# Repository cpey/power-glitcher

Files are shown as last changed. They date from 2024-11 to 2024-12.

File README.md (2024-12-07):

# Power Glitcher

Power glitcher circuit for voltage fault injection. Similar to [1], it includes
a DAC, a non-inverting amplification stage, and a push-pull follower output
circuit.

The board can function as ON/OFF switch, bypassing the DAC, by connecting a GPIO
output to the J5 connector and short-circuiting JP1. Refer to the
[schematic](https://github.com/cpey/power-glitcher/blob/main/power_glitcher/power_glitcher.pdf)
for more details.

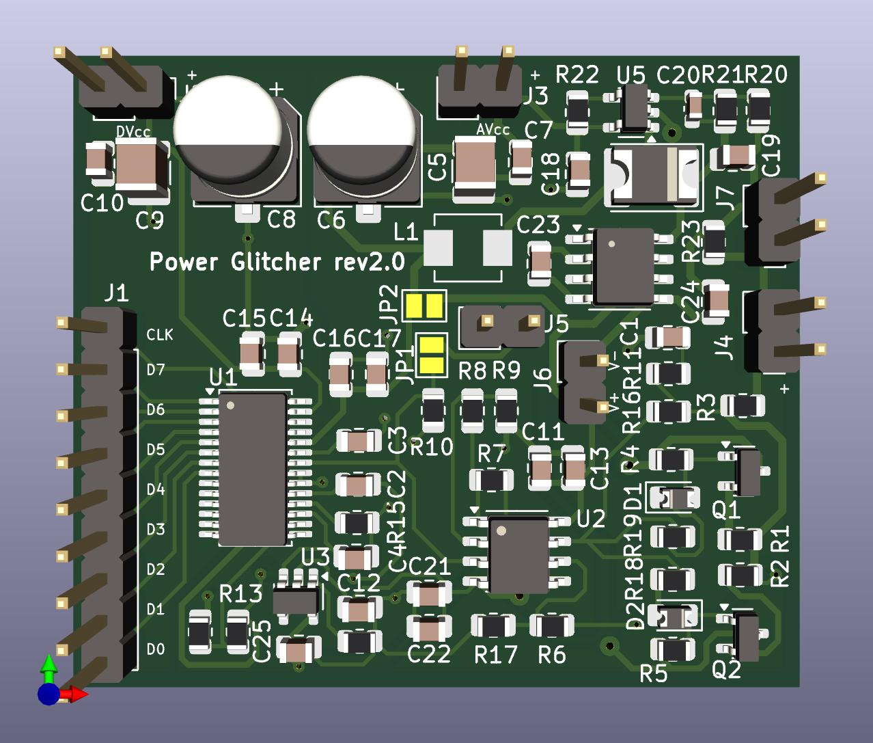
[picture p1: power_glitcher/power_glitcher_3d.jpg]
Rendered 3D view of the Power Glitcher.


[1] D. Oswald, *A Versatile Framework for Implementation Attacks on Cryptographic RFIDs and Embedded Devices*, 2010.

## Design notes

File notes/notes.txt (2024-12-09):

* Source: The Art of Electronics
+ Crossover distortion in push-pull stages (Page 107)
+ Thermal stability in class-B push-pull amplifiers (Page 108)

- Considering load: 500 mA, 5V
- Power = 2.5 W
- Beta = 50
- B = Ic/Ib => Ib = Ic / B = 500e-3 / 50. = 0.01 A = 10 mA (base current)
- peak base current = 5V, Vcc = 15V => R = 10V / 10 mA = 1K
- peak base current = 5V, Vcc = 7.5V => R = 2.5V / 10 mA = 250

* Power booster (page 234)

* LM2735: vout = 7.5 V

10% ripple: Ail => 10% of max load = 10% of .5 A = 0.05 A
20% ripple: Ail => 10% of max load = 10% of .5 A = 0.1 A
1/Ts = Fsw (switching frequency: 1.6MHz) => Ts = 1/1.6MHz = 6.25e-7 = 0.625e-6
D = (Vout - Vin) / Vout = (7.5 - 5) / 7.5 = 0.33
10% ripple: L = (Vin / (2 * Ail)) * D*Ts = (5 / (2 * 0.05)) * 0.33 * 0.625e-6 = 10.31 uH
20% ripple: L = (Vin / (2 * Ail)) * D*Ts = (5 / (2 * 0.1)) * 0.33 * 0.625e-6 = 5.15 uH
Rload = 7.5 V / 0.5 A = 15 Ohm
R1 = 10 K
Vref = 1.255 V
R2 = ( Vout / Vref - 1 ) * R1 = 49760 ohm ~ 49.9KOhm  

https://webench.ti.com/power-designer/switching-regulator/select

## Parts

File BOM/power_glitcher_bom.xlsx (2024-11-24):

Index | Quantity | Part Number | Manufacturer Part Number | Description | Customer Reference | Available | Backorder | Unit Price | Extended Price USD
1 | 10 | A105951CT-ND | LR1F1K0 | RES 1K OHM 1% 0.6W AXIAL |  | 10 | 0 | 0.054 | 0.54
2 | 2 | 2449-J107F1CS1212VDC.36-ND | J107F1CS1212VDC.36 | RELAY GEN PURPOSE SPDT 12A 12V |  | 2 | 0 | 1.09 | 2.18
3 | 1 | 497-14098-ND | STM32F072B-DISCO | DISCOVERY STM32 F0 EVAL BRD |  | 1 | 0 | 11.3 | 11.30
4 | 1 | 497-14594-ND | NUCLEO-F302R8 | NUCLEO-64 STM32F302R8 EVAL BRD |  | 1 | 0 | 11.01 | 11.01
5 | 2 | 1835-1055-ND | 3570-1419-054 | RELAY REED SIP SPST 1A 5V W/EMI |  | 2 | 0 | 3.19 | 6.38
6 | 2 | AD8058ARZ-REEL7CT-ND | AD8058ARZ-REEL7 | IC VOLTAGE FEEDBACK 2 CIRC 8SOIC |  | 2 | 0 | 6.96 | 13.92
7 | 10 | BC817-25LT1GOSCT-ND | BC817-25LT1G | TRANS NPN 45V 0.5A SOT23-3 |  | 10 | 0 | 0.069 | 0.69
8 | 10 | BC807-40LT3GOSCT-ND | BC807-40LT3G | TRANS PNP 45V 0.5A SOT23-3 |  | 10 | 0 | 0.071 | 0.71
9 | 2 | AD9708ARUZ-ND | AD9708ARUZ | IC DAC 8BIT A-OUT 28TSSOP |  | 2 | 0 | 16.24 | 32.48
10 | 2 | 497-10010-1-ND | STS10N3LH5 | MOSFET N-CH 30V 10A 8SO |  | 2 | 0 | 1.32 | 2.64
11 | 10 | 296-TL081HIDBVRCT-ND | TL081HIDBVR | IC OPAMP JFET 1 CIRCUIT SOT23-5 |  | 10 | 0 | 0.139 | 1.39
12 | 10 | 732-8419-1-ND | 865080343009 | CAP ALUM 100UF 20% 16V SMD |  | 10 | 0 | 0.28 | 2.80
13 | 10 | 399-3686-1-ND | T491A106M010AT | CAP TANT 10UF 20% 10V 1206 |  | 10 | 0 | 0.217 | 2.17
14 | 30 | 311-1140-1-ND | CC0805KRX7R9BB104 | CAP CER 0.1UF 50V X7R 0805 |  | 30 | 0 | 0.058 | 1.74
15 | 20 | 311-1365-1-ND | CC0805KKX7R7BB105 | CAP CER 1UF 16V X7R 0805 |  | 20 | 0 | 0.069 | 1.38
16 | 20 | RNCP0805FTD1K00CT-ND | RNCP0805FTD1K00 | RES 1K OHM 1% 1/4W 0805 |  | 20 | 0 | 0.027 | 0.54
17 | 20 | 311-270CRCT-ND | RC0805FR-07270RL | RES 270 OHM 1% 1/8W 0805 |  | 20 | 0 | 0.016 | 0.32
18 | 20 | P2.00KCCT-ND | ERJ-6ENF2001V | RES SMD 2K OHM 1% 1/8W 0805 |  | 20 | 0 | 0.052 | 1.04
19 | 20 | RMCF0805FT100RCT-ND | RMCF0805FT100R | RES 100 OHM 1% 1/8W 0805 |  | 20 | 0 | 0.021 | 0.42
20 | 2 | 118-PV36W500C01B00-ND | PV36W500C01B00 | TRIMMER 50 OHM 0.5W PC PIN TOP |  | 2 | 0 | 1.89 | 3.78
21 | 2 | 1835-1118-ND | 3570-1331-121 | RELAY REED SIP SPST .5A 12V |  | 2 | 0 | 1.7 | 3.40
22 | 2 | LM2735XMF/NOPBCT-ND | LM2735XMF/NOPB | IC REG BOOST FLYBACK ADJ SOT23-5 |  | 2 | 0 | 2.85 | 5.70
23 | 10 | 445-1420-1-ND | C2012X7R1C225K125AB | CAP CER 2.2UF 16V X7R 0805 |  | 10 | 0 | 0.108 | 1.08
24 | 20 | 1276-1096-1-ND | CL21A106KOQNNNE | CAP CER 10UF 16V X5R 0805 |  | 20 | 0 | 0.051 | 1.02
25 | 10 | 13-AC0603JRNPO0BN102CT-ND | AC0603JRNPO0BN102 | CAP 0603 100V 1 NF NPO |  | 10 | 0 | 0.081 | 0.81
26 | 20 | RNCP0805FTD10K0CT-ND | RNCP0805FTD10K0 | RES 10K OHM 1% 1/4W 0805 |  | 20 | 0 | 0.027 | 0.54
27 | 20 | RNCP0805FTD49K9CT-ND | RNCP0805FTD49K9 | RES 49.9K OHM 1% 1/4W 0805 |  | 20 | 0 | 0.027 | 0.54
28 | 3 | SRP4020TA-5R6MCT-ND | SRP4020TA-5R6M | FIXED IND 5.6UH 2.2A 125MOHM SMD |  | 3 | 0 | 1.21 | 3.63
29 | 5 | B140HB-FDICT-ND | B140HB-13-F | DIODE SCHOTTKY 40V 1A SMB |  | 5 | 0 | 0.36 | 1.80
30 | 3 | ICL7660ACBAZA-TCT-ND | ICL7660ACBAZA-T | IC REG CHARG PUMP INV 45MA 8SOIC |  | 3 | 0 | 2.96 | 8.88
31 | 20 | 541-1.00TCT-ND | CRCW08051R00FKEAHP | RES SMD 1 OHM 1% 1/2W 0805 |  | 20 | 0 | 0.142 | 2.84
32 | 25 | 311-0.0ARCT-ND | RC0805JR-070RL | RES 0 OHM JUMPER 1/8W 0805 |  | 25 | 0 | 0.0116 | 0.29
33 | 10 | 478-SD0805S040S1R0CT-ND | SD0805S040S1R0 | DIODE SCHOTTKY 40V 1A 0805 |  | 10 | 0 | 0.2 | 2.00

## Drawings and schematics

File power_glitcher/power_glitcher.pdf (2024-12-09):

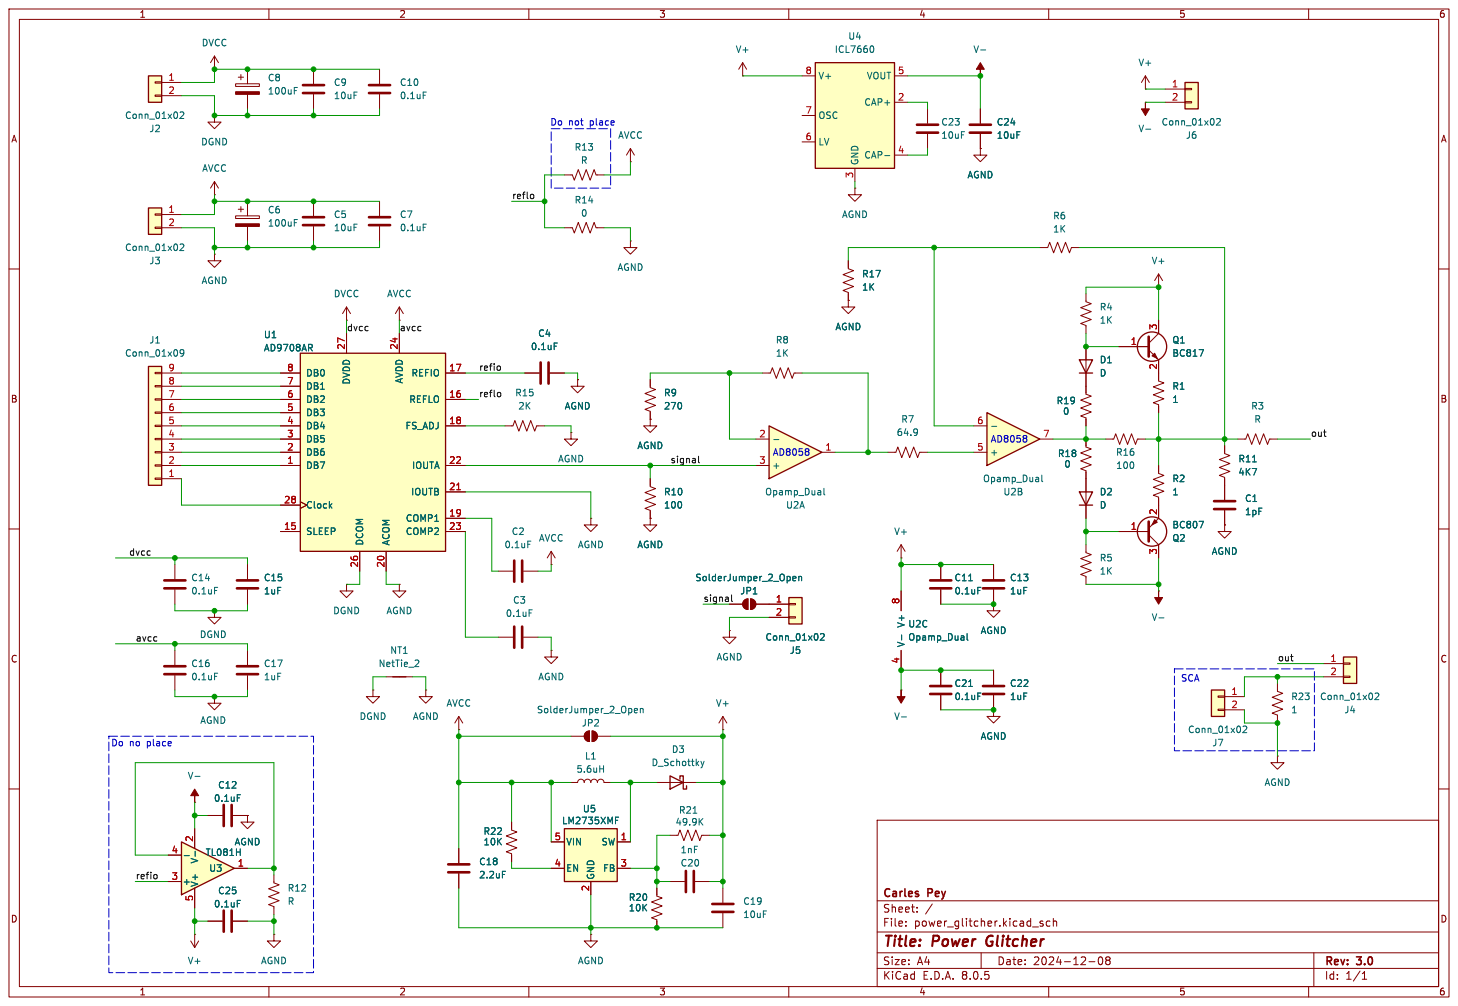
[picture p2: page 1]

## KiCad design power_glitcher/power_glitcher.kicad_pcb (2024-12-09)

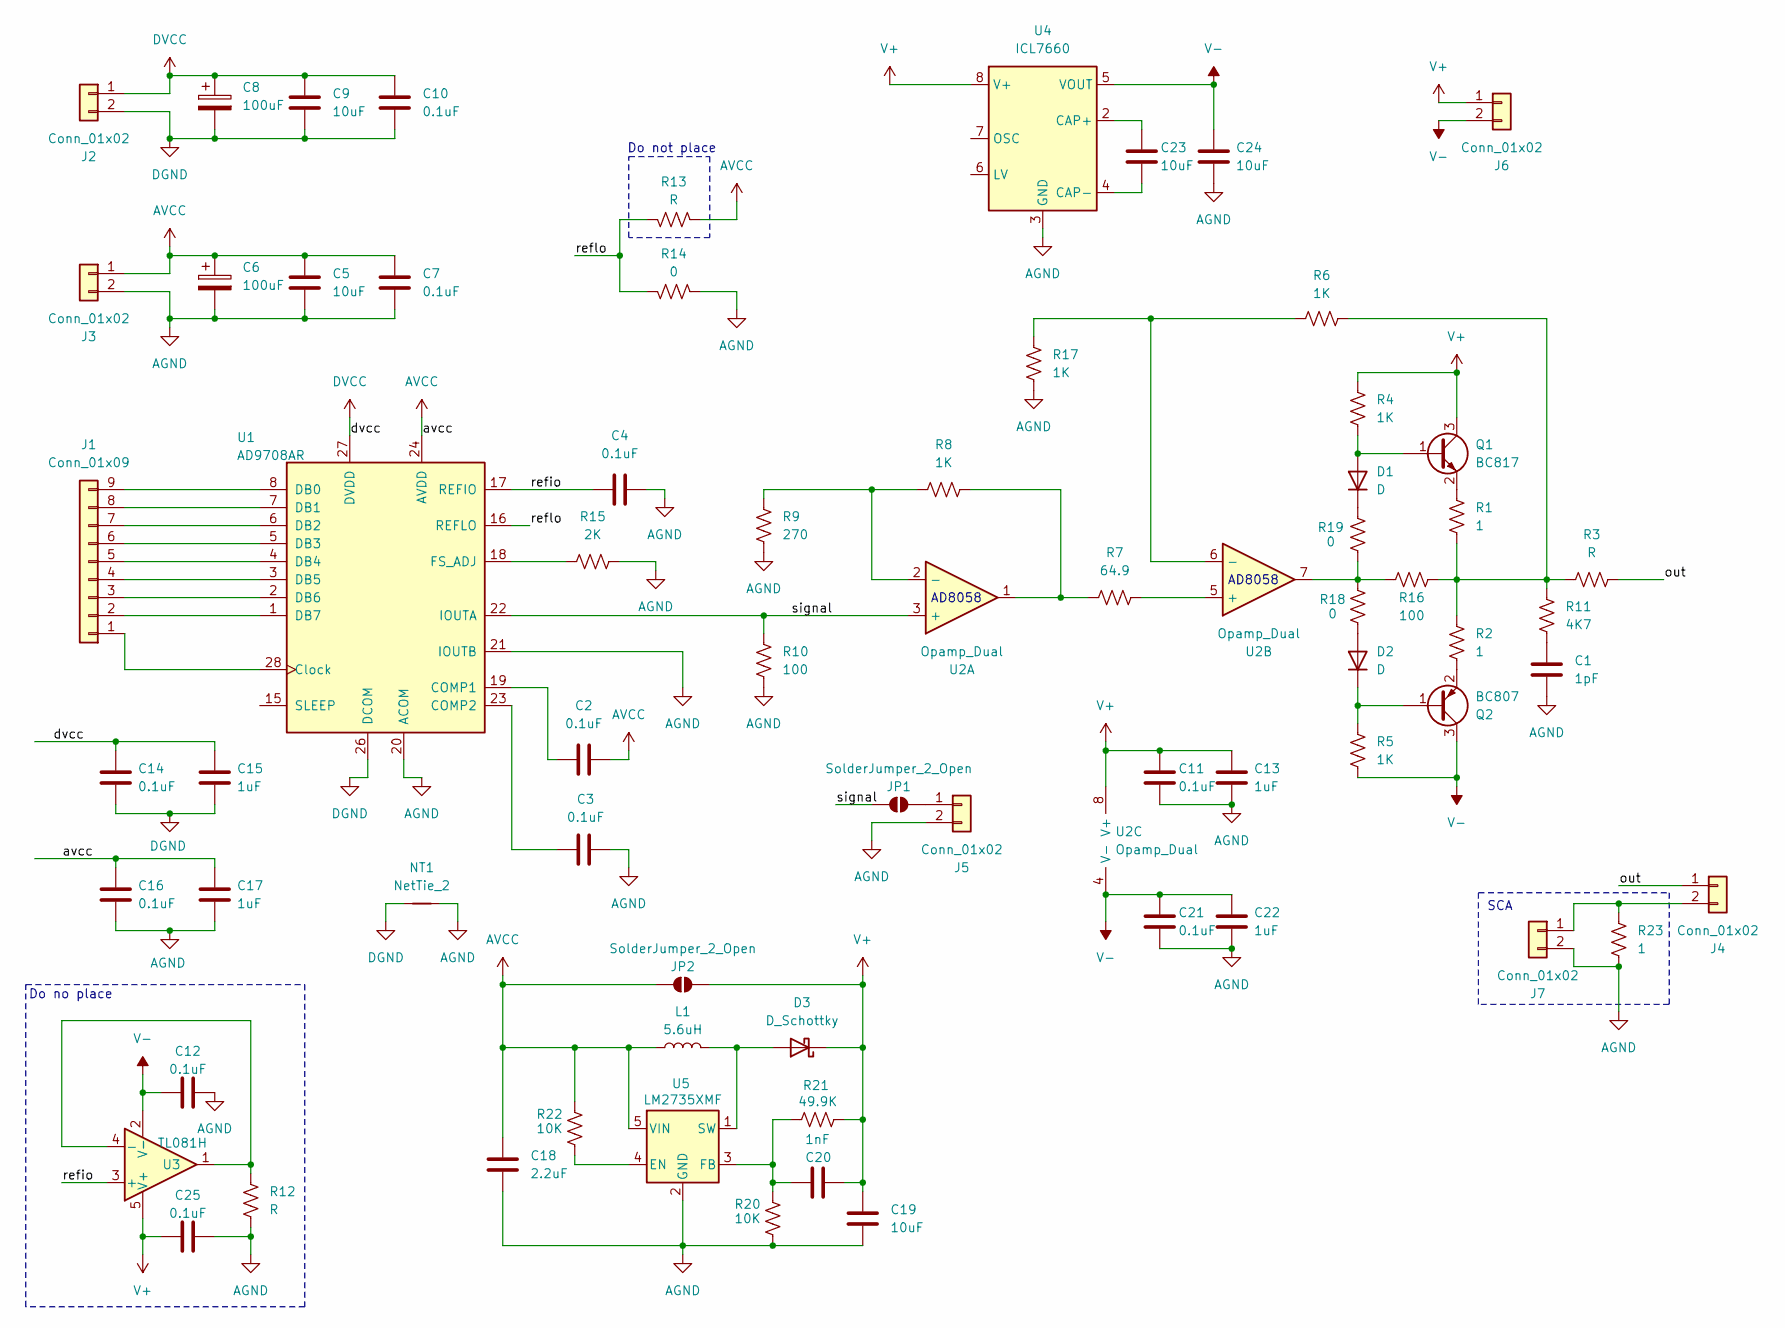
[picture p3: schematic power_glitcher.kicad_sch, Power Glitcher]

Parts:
C1: 1pF; C_0805_2012Metric
C2, C3, C4, C7, C10, C11, C12, C14, C16, C21, C25: 0.1uF; C_0805_2012Metric
C5, C9: 10uF; C_1210_3225Metric
C6, C8: 100uF; CP_Elec_6.3x5.8
C13, C15, C17, C22: 1uF; C_0805_2012Metric
C18: 2.2uF; C_0805_2012Metric
C19, C23, C24: 10uF; C_0805_2012Metric
C20: 1nF; C_0603_1608Metric
D1, D2: D; D_0805_2012Metric_Pad1.15x1.40mm_HandSolder
D3: D_Schottky; D_2114_3652Metric
J1: Conn_01x09; PinHeader_1x09_P2.54mm_Vertical
J2, J3, J4, J5, J6, J7: Conn_01x02; PinHeader_1x02_P2.54mm_Vertical
JP1, JP2: SolderJumper_2_Open; SolderJumper-2_P1.3mm_Open_Pad1.0x1.5mm
L1: 5.6uH; L_Vishay_IHLP-1616
NT1: NetTie_2; NetTie-2_SMD_Pad0.5mm
Q1: BC817; SOT-23
Q2: BC807; SOT-23
R1, R2, R23: 1; R_0805_2012Metric
R3, R12, R13: R; R_0805_2012Metric
R4, R5, R6, R8, R17: 1K; R_0805_2012Metric
R7: 64.9; R_0805_2012Metric
R9: 270; R_0805_2012Metric
R10, R16: 100; R_0805_2012Metric
R11: 4K7; R_0805_2012Metric
R14, R18, R19: 0; R_0805_2012Metric
R15: 2K; R_0805_2012Metric
R20, R22: 10K; R_0805_2012Metric
R21: 49.9K; R_0805_2012Metric
U1: AD9708AR; TSSOP-28_4.4x9.7mm_P0.65mm
U2: Opamp_Dual; SOIC-8_3.9x4.9mm_P1.27mm
U3: TL081H; SOT-23-5
U4: ICL7660; SO-8_3.9x4.9mm_P1.27mm
U5: LM2735XMF; SOT-23-5

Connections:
/out: J4.1, R3.2
/refio: C4.1, U1.17 (REFIO), U3.3 (+)
/reflo: R13.1, R14.1, U1.16 (REFLO)
/signal: JP1.2 (B), R10.2, U1.22 (IOUTA), U2.3 (+)
AGND: C1.2, C3.2, C4.2, C5.2, C6.2, C7.2, C11.2, C12.2, C13.2, C16.2, C17.2, C18.1, C19.1, C21.2, C22.2, C24.2, C25.1, J3.2, J5.2, J7.2, NT1.2, R9.1, R10.1, R12.1, R14.2, R15.1, R17.1, R20.1, R23.1, U1.20 (ACOM), U1.21 (IOUTB), U4.3 (GND), U5.2 (GND)
AVCC: C2.2, C5.1, C6.1, C7.1, C16.1, C17.1, C18.2, J3.1, JP2.2 (B), L1.1, R13.2, R22.2, U1.24 (AVDD), U5.5 (VIN)
DGND: C8.2, C9.2, C10.2, C14.2, C15.2, J2.2, NT1.1, U1.26 (DCOM)
DVCC: C8.1, C9.1, C10.1, C14.1, C15.1, J2.1, U1.27 (DVDD)
unnamed: C1.1, R11.1
unnamed: D1.2 (A), Q1.1 (B), R4.1
unnamed: D1.1 (K), R19.2
unnamed: D2.2 (A), R18.1
unnamed: D2.1 (K), Q2.1 (B), R5.2
unnamed: D3.2 (A), L1.2, U5.1 (SW)
unnamed: J1.1, U1.28 (Clock)
unnamed: J1.2, U1.1 (DB7)
unnamed: J1.3, U1.2 (DB6)
unnamed: J1.4, U1.3 (DB5)
unnamed: J1.5, U1.4 (DB4)
unnamed: J1.6, U1.5 (DB3)
unnamed: J1.7, U1.6 (DB2)
unnamed: J1.8, U1.7 (DB1)
unnamed: J1.9, U1.8 (DB0)
unnamed: J4.2, J7.1, R23.2
unnamed: J5.1, JP1.1 (A)
unnamed: Q1.2 (E), R1.1
unnamed: Q2.2 (E), R2.2
unnamed: R1.2, R2.1, R3.1, R6.2, R11.2, R16.2
unnamed: R7.1, R8.2, U2.1
unnamed: R16.1, R18.2, R19.1, U2.7
unnamed: C2.1, U1.19 (COMP1)
unnamed: C3.1, U1.23 (COMP2)
unnamed: R15.2, U1.18 (FS_ADJ)
unnamed: R8.1, R9.2, U2.2 (-)
unnamed: R7.2, U2.5 (+)
unnamed: R6.1, R17.2, U2.6 (-)
unnamed: R12.2, U3.1, U3.4 (-)
unnamed: C23.1, U4.2 (CAP+)
unnamed: C23.2, U4.4 (CAP-)
unnamed: R22.1, U5.4 (EN)
unnamed: C20.2, R20.2, R21.1, U5.3 (FB)
V+: C11.1, C13.1, C19.2, C20.1, C25.2, D3.1 (K), J6.1, JP2.1 (A), Q1.3 (C), R4.2, R21.2, U2.8 (V+), U3.5 (V+), U4.8 (V+)
V-: C12.1, C21.1, C22.1, C24.1, J6.2, Q2.3 (C), R5.1, U2.4 (V-), U3.2 (V-), U4.5 (VOUT)

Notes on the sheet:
AD8058
SCA
Do not place
Do no place

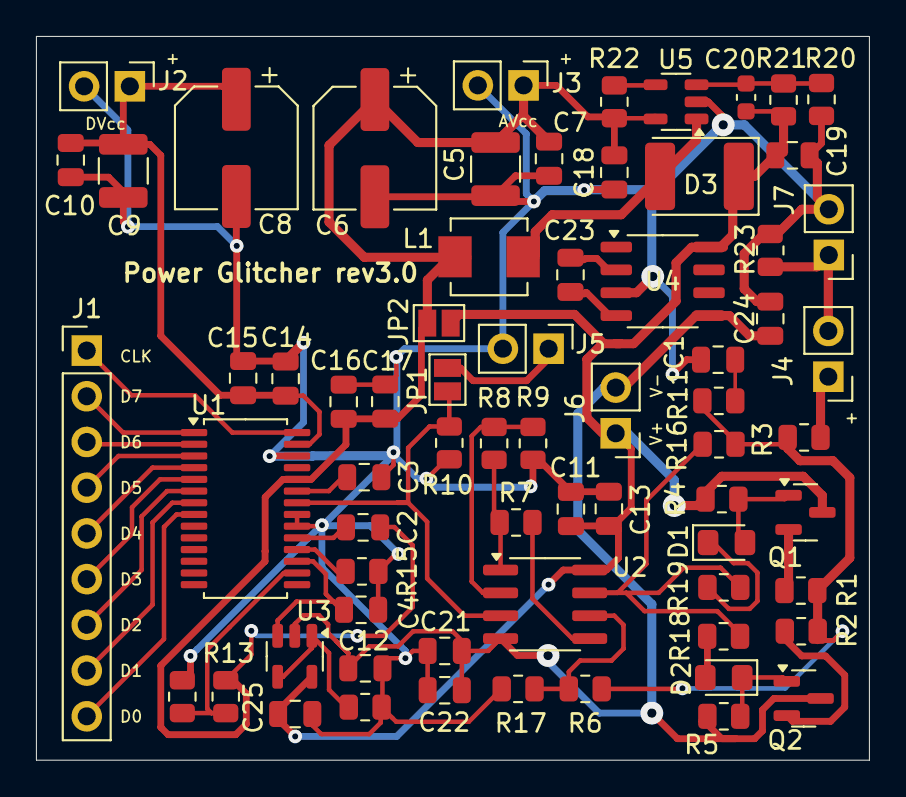
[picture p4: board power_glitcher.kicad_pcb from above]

Board: 2 copper layers, 46.3 x 40.2 mm, 69 parts (1 on the bottom side), 43 nets.

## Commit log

2024-11-18 Rev 2.0
    [power_glitcher-B_Cu.gbr, power_glitcher-B_Mask.gbr, power_glitcher-B_Paste.gbr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]
2024-11-24 Update BOM
    [2024-10-20T110737.xlsx, power_glitcher.kicad_sch, power_glitcher_bom.xlsx]
2024-12-09 Add bypass jumper for LM2735 and power analysis capability
    [power_glitcher-B_Cu.gbr, power_glitcher-B_Mask.gbr, power_glitcher-B_Paste.gbr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]
